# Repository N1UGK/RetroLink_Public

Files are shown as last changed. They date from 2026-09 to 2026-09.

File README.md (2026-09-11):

# RetroLink (POTS Telephone Internet Interface)

RetroLink connects a standard POTS (Plain Old Telephone Service) analog telephone to the Internet over Wi-Fi, allowing peer-to-peer calling between devices and retro telephony interfacing.  The RetroLink is intended for private telephone networks in the same building, campus, or even across the globe.  It will not require subscription fees or a third party "app" or platform to use.  The idea came from my daughter (who is 6) asking for a phone to call her friends.  This device can be configured for connecting a close circle of friends or family and using their chosen "phone number" to dial and connect to them.  Any standard "retro" telephone can be plugged into the RetroLink.

RetroLink

## Overview

RetroLink provides a complete, self-contained telephone line interface for real analog telephones (both rotary and DTMF touch-tone). It generates real ringing voltages, provides line battery feed, detects off-hook and on-hook states, digitizes 2-wire voice audio with hardware codecs, and streams bidirectional voice data over Wi-Fi.

## Key Features

- **True POTS Line Interface**: Powered by the **Silvertel Ag1170-S5** SLIC with an onboard DC/DC converter generating -48V loop battery and 65Vrms ringing directly from a 5V supply.
- **Hardware Voice Codec**: **Texas Instruments TLV320AIC1110** providing 8 kHz PCM sampling, companded G.711 µ-law encoding, digital PGA gain control, and programmable sidetone.
- **Microcontroller**: **Raspberry Pi Pico 2 W** (RP2350 with dual ARM Cortex-M33 / Hazard3 RISC-V cores and onboard CYW43 Wi-Fi).
- **Dual-Core Architecture**:
  - **Core 0**: Real-time audio engine with DMA/PIO double buffering, low-latency audio packetization, and SLIC line supervision (hook switch debounce & ring cadence).
  - **Core 1**: CYW43 Wi-Fi stack, lwIP networking, VoIP stream/control protocol, web status interface, and OLED display navigation.
- **User Interface**:
  - 128x64 SSD1306 OLED display via I2C (0x3C)
  - 4-button tactile keypad (Up, Down, OK, Back) via MAX7329 GPIO expander (0x3A)
  - 7 Status LEDs (Off-Hook, MicroSD, Voice Mail, Ringing, Connected, Wi-Fi Link, Error) via MAX7329 (0x38)
- **Local Storage & USB**:
  - MicroSD card slot over SPI0 with FatFS for address books, call logs, and voicemail storage.
  - TinyUSB USB Mass Storage support for mounting the SD card on a PC or Mac.
- **Web Dashboard & Control**:
  - Embedded HTTP server for real-time OLED screen viewing, virtual button control, device status, and network configuration.
- **Secure Firmware Updates**:
  - Dedicated 64 KB custom bootloader with OTP key verification and drag-and-drop UF2 updates over USB.

## Hardware Specifications

| Component | Specification |
|---|---|
| Microcontroller | Raspberry Pi Pico 2 W (RP2350 @ 150MHz) |
| SLIC Module | Silvertel Ag1170-S5 (5V, 600Ω 2-wire impedance) |
| Ring Generator | Onboard Ag1170 ringing (65Vrms @ 20Hz, REN 3 capable) |
| Voice Codec | TI TLV320AIC1110 (PCM / G.711 µ-law, 8 kHz) |
| Display | 0.96" 128x64 I2C OLED (0x3C) |
| I/O Expanders | 2x MAX7329 I2C Expanders (0x38, 0x3A) |
| Power Supply | Single 18650 Li-Ion Cell with BQ24090 Charger & MCP1642B 5V Boost |
| Connector | Standard RJ-11 6P4C Modular Phone Jack |

## Firmware Updates

To update the firmware:
1. Place RetroLink into bootloader mode via the OLED menu: `Settings -> Update Firmware`, or hold the bootsel/startup button combo on power-up.
2. Connect RetroLink to your computer via USB. A mass-storage drive named `RETROLINK` will appear.
3. Drag and drop the latest release `.uf2` file from the `Firmware/` folder onto the drive.
4. The bootloader will verify and flash the image, then automatically reboot into the new firmware.

## Repository Structure

- `Firmware/`: Official firmware release binaries (`.uf2`) and release notes.
- `Hardware/`: 3D CAD STEP models, schematics, and mechanical design files.
- `Documentation/`: User guides, application notes, and reference manuals.
>>>>>>> b99fa2f (Initial commit for RetroLink_Public repository structure)

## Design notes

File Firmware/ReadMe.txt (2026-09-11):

RetroLink Firmware Release Notes

Note - In order to update the firmware, you will need to place the RetroLink into bootloader mode. This can be done via the OLED display menu: Settings -> Update Firmware, or by holding the configured startup button combination on power-up.

RetroLink will reboot into its bootloader mode. Plug RetroLink into a Mac or PC with a USB cable, and drag and drop the firmware file onto the removable drive that appears.

The RetroLink bootloader will decrypt the firmware file, verify the signature, and if it passes, it will flash the image and reboot.

Note that the RetroLink bootloader is distinct from the default RP2350 ROM bootloader — if you use the BOOTSEL button on the Pico 2 W directly, the ROM bootloader cannot decrypt signed RetroLink firmware images. You can determine which bootloader is active by checking the directory contents of the USB drive:
- If you see `RetroLink.txt` / `INFO_UF2.TXT` with RetroLink identifiers, you are in the RetroLink Custom Bootloader.
- If you see default Raspberry Pi files, you are in the RP2350 ROM bootloader.

--------------------------------------------------------------------------------
09-11-2026 - RetroLink_V1.00_B0001.uf2

- Initial firmware release shell for RetroLink (Raspberry Pi Pico 2 W / RP2350).
- Drivers:
  - Ag1170 SLIC: hook switch detection, debounce, ring-trip auto-cancel, 20Hz ring cadence generator, power down.
  - TLV320AIC1110 voice codec: 8 kHz PCM sampling, I2C register configuration, PGA volume/gain controls.
  - SSD1306 128x64 OLED display: real-time status display and menu navigation.
  - MAX7329 I/O expanders: 4 tactile buttons and 7 status LEDs (OH, SD, VM, RNG, CON, LNK, ERR).
  - SD Card / FatFS: SPI0 storage with USB Mass Storage bridge.
  - Wi-Fi & Web UI: CYW43 Wi-Fi connection, SNTP network time sync, and remote HTTP status dashboard.

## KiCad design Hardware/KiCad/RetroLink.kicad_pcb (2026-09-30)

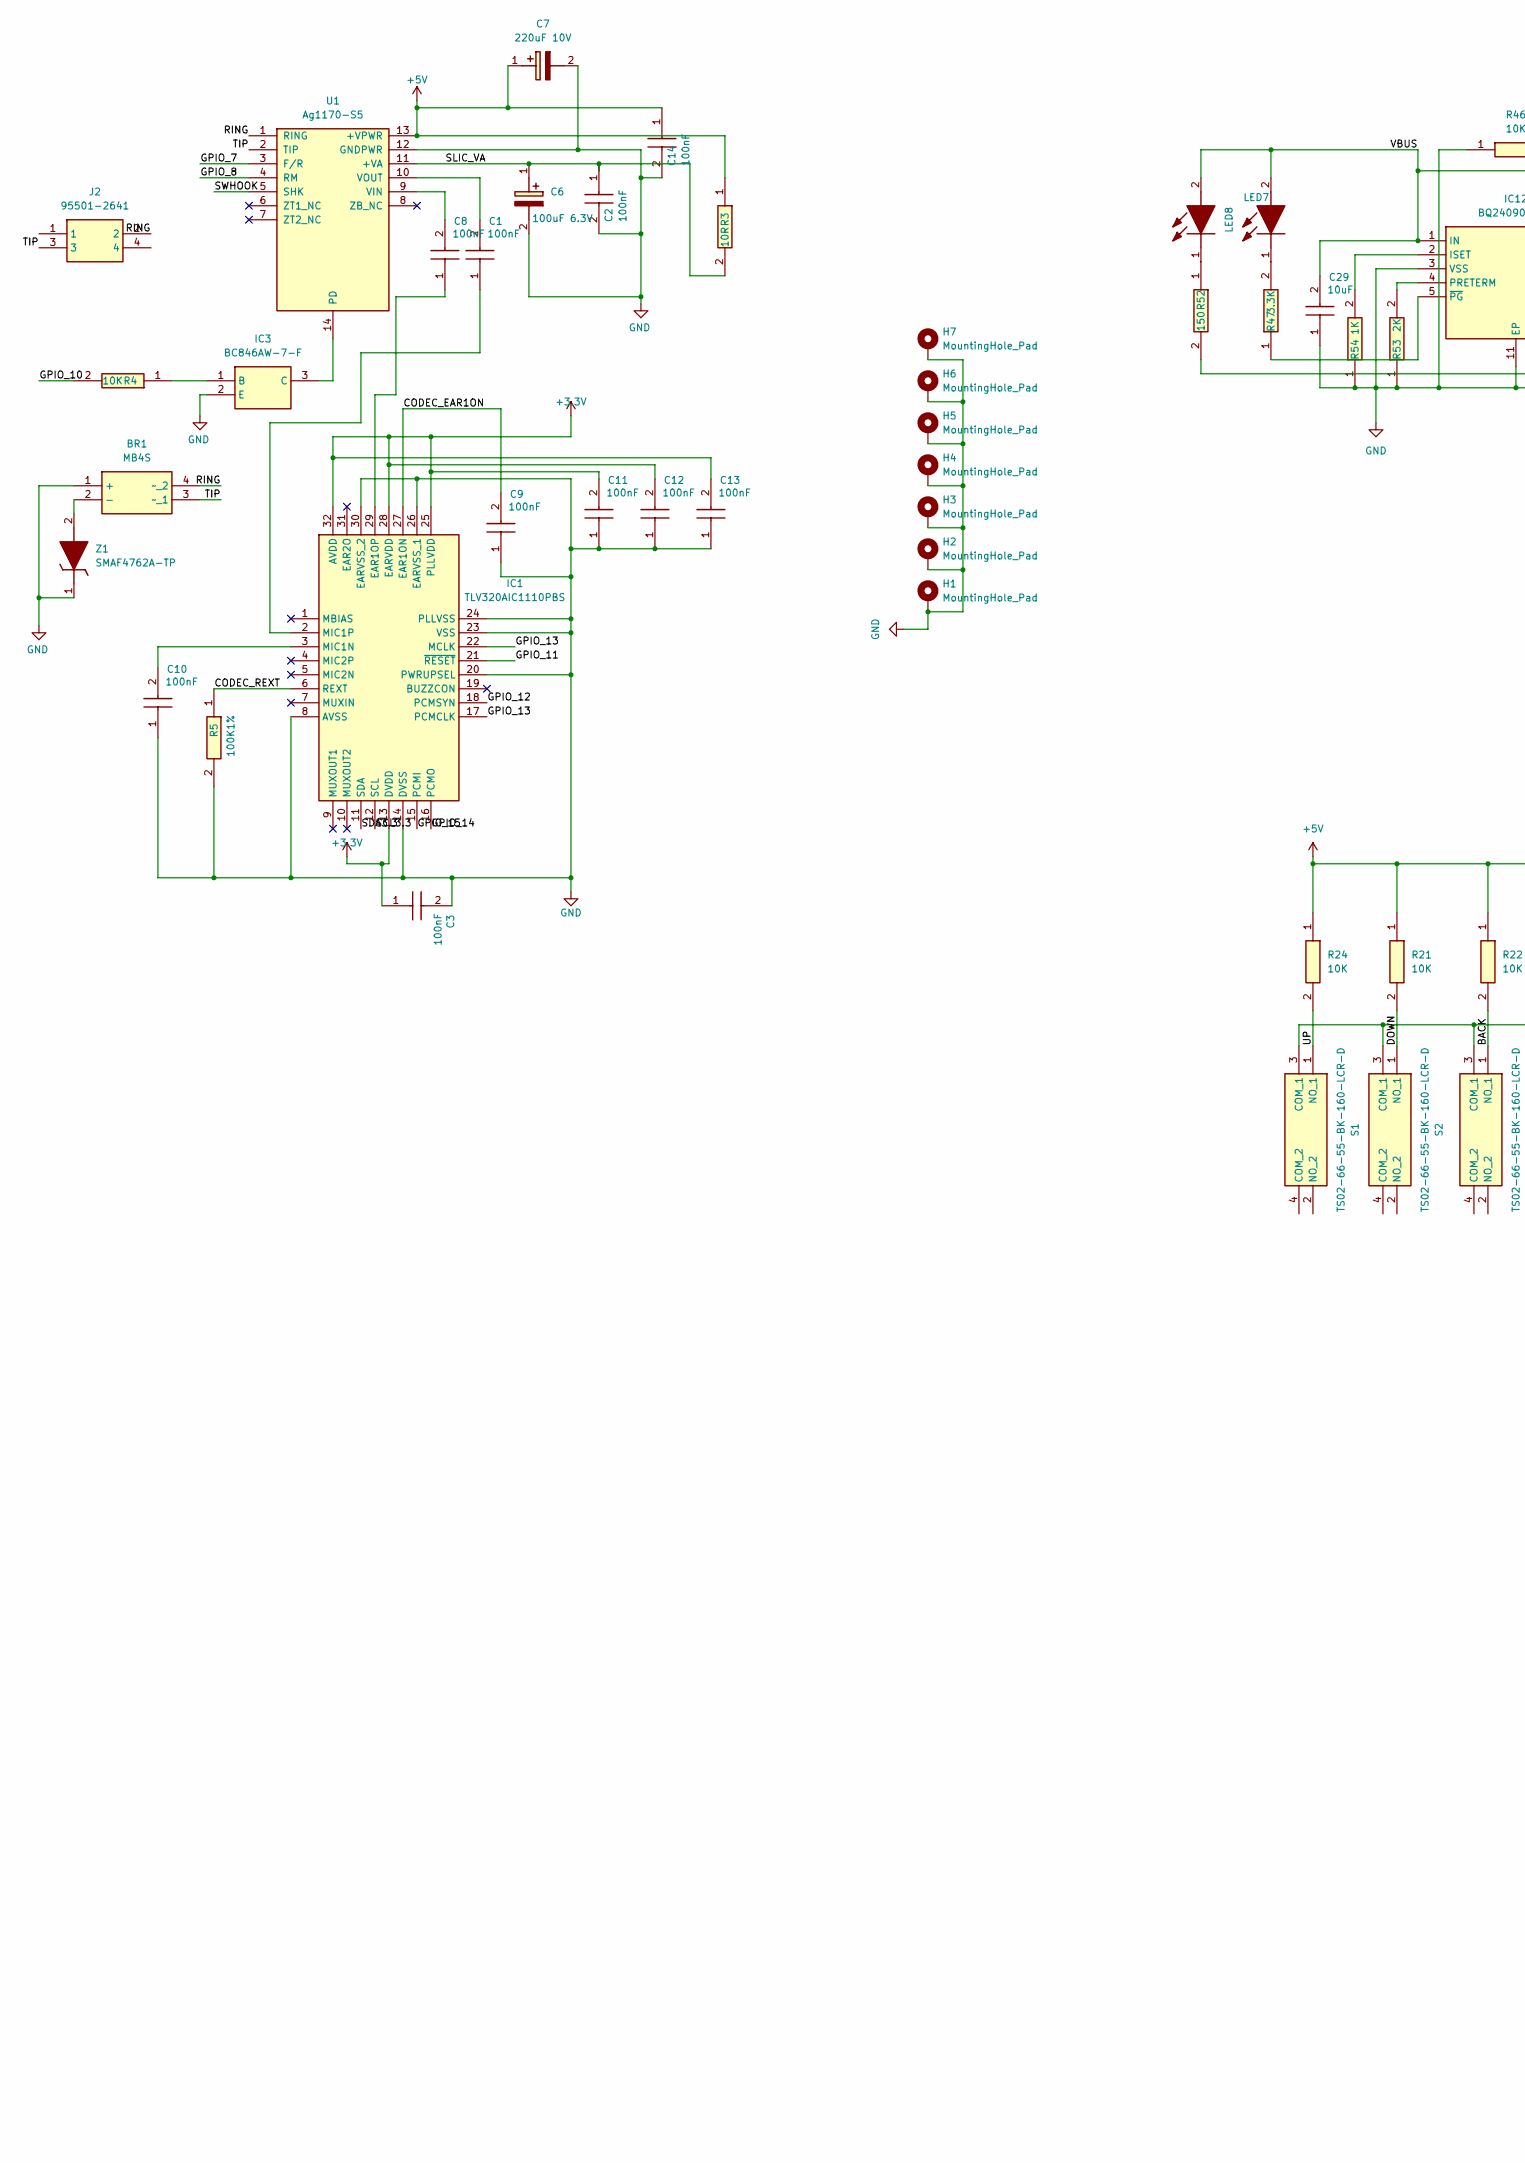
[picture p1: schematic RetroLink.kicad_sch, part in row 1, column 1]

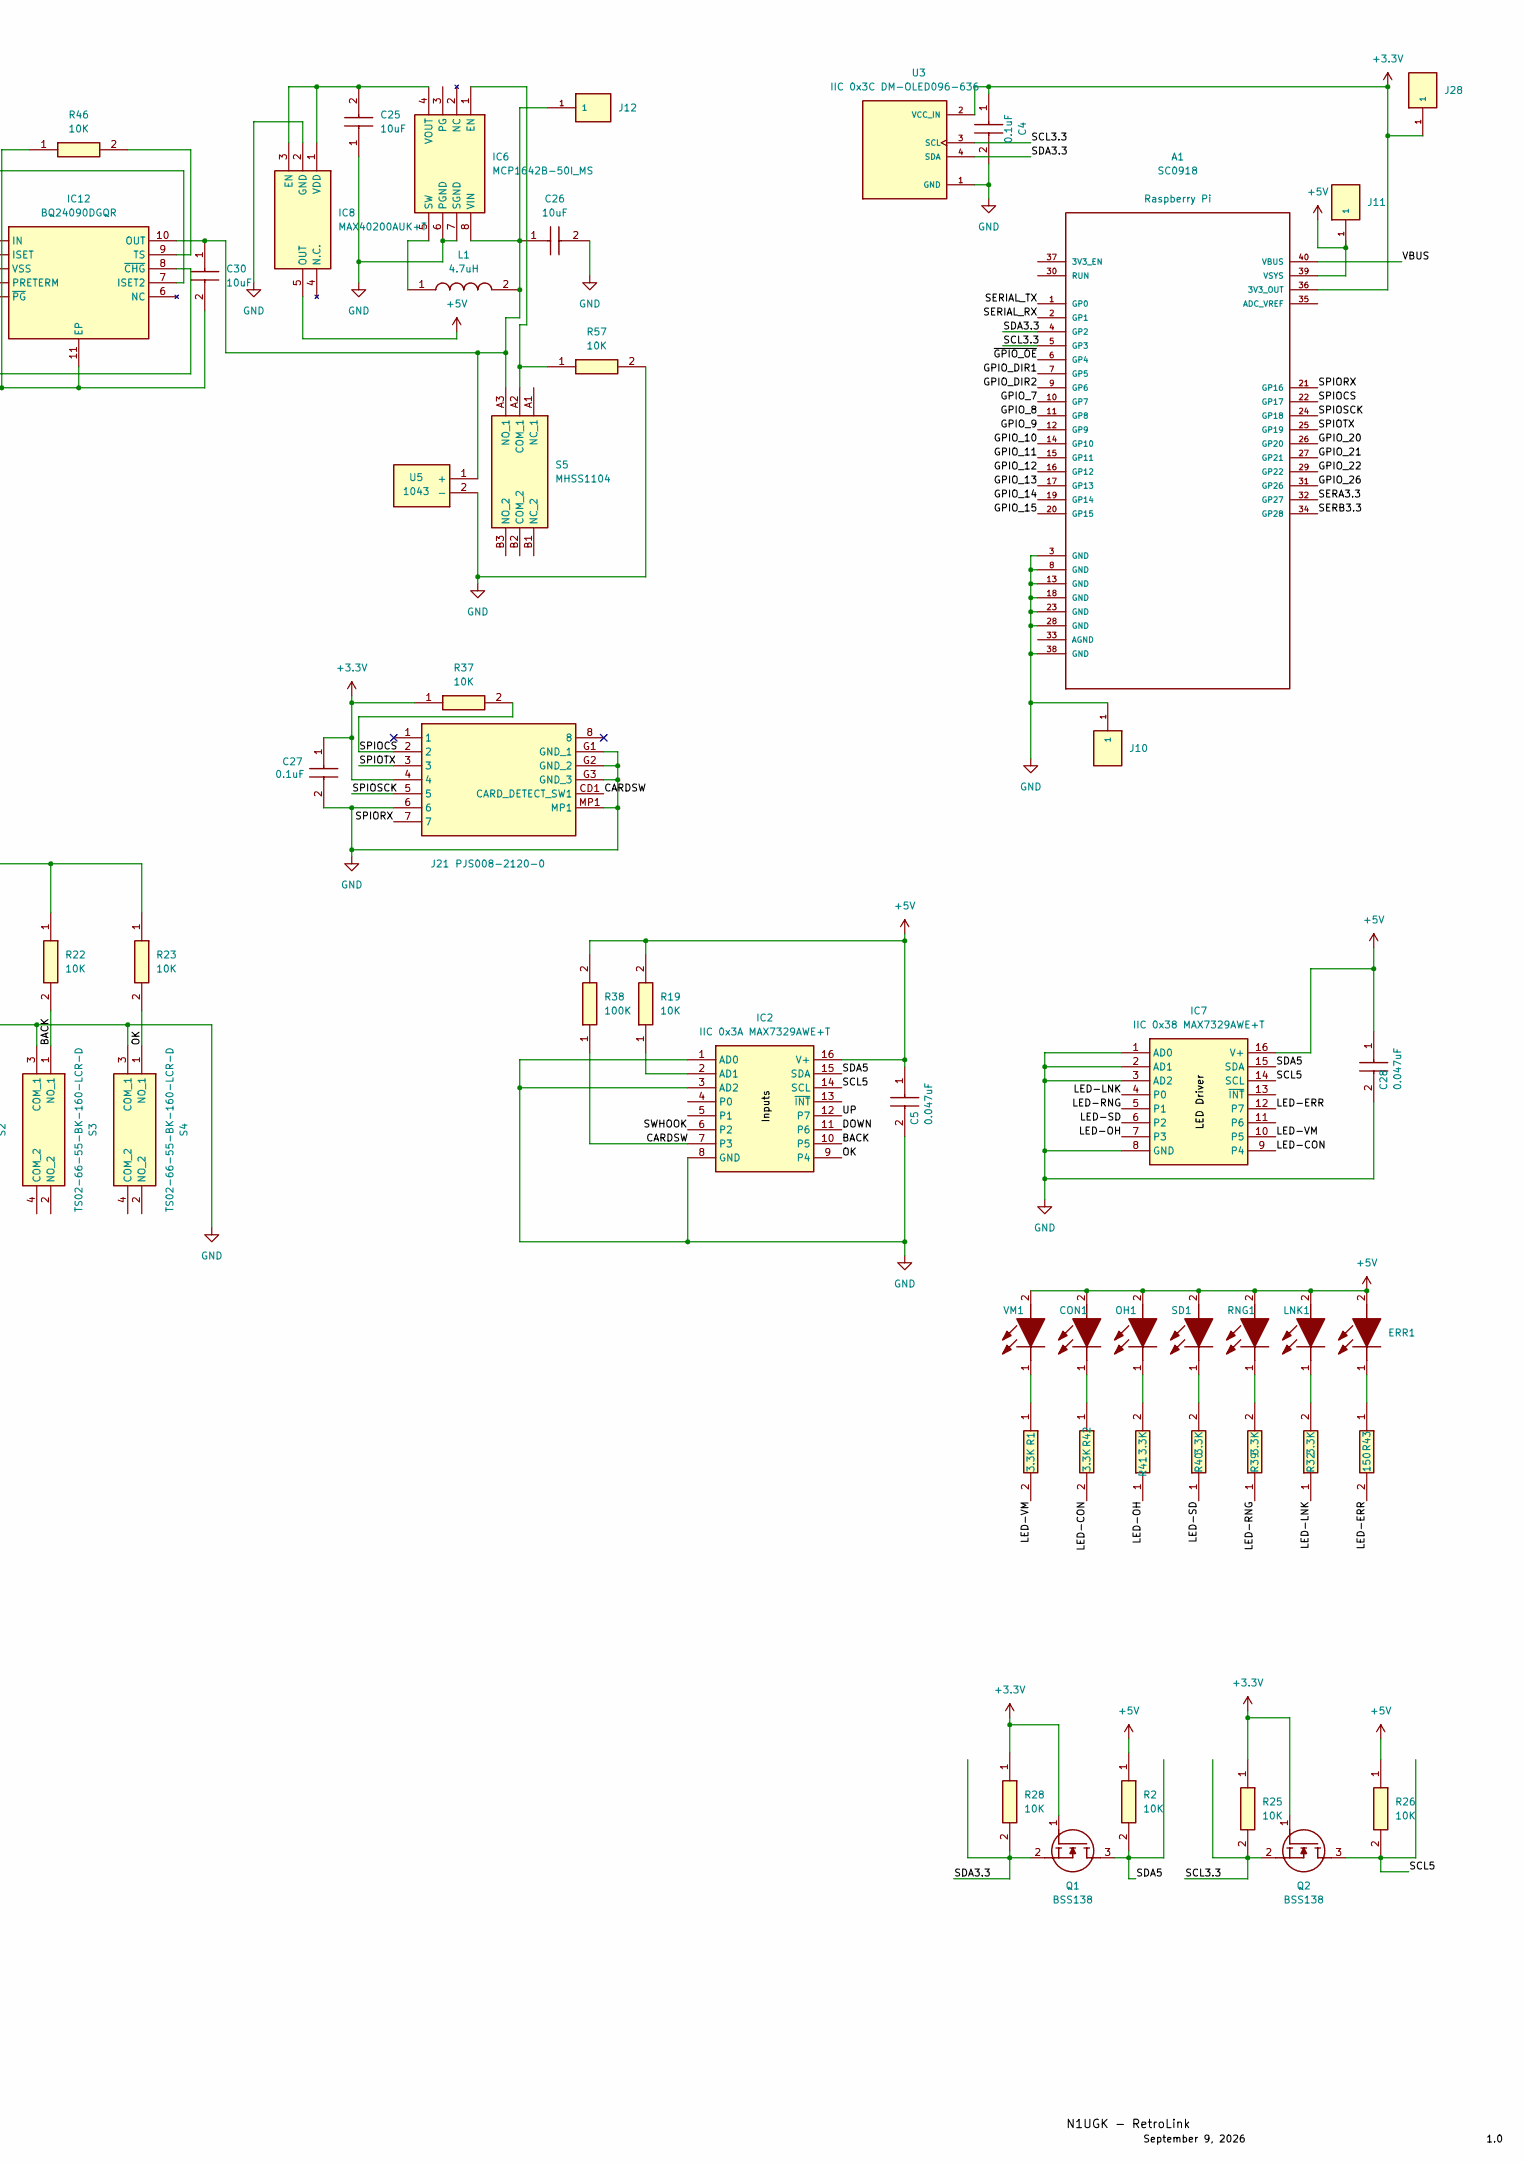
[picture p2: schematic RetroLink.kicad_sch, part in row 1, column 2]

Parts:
A1: SC0918; MODULE_SC0918; PARTREV 1.6
BR1: MB4S; SOP245P670X290-4N; Mouser Part Number 512-MB4S
C1, C3, C8, C9, C10, C11, C12, C13: 100nF; CAPC1608X90N; Mouser Part Number 81-GRM188R60J106ME4D
C2, C14: 100nF; C1206; Mouser Part Number 80-C1206C473J5R
C4: 0.1uF; CAPC3216X229N; Mouser Part Number 581-12063G106ZAT2A
C5, C28: 0.047uF; C1206; Mouser Part Number 80-C1206C473J5R
C6: 100uF 6.3V; CAPPRD200W50D500H1250; Mouser Part Number 80-ESK107M025AC3AA
C7: 220uF 10V; CAPPRD250W50D655H1250; Mouser Part Number 232-16ZLH220MEFC63X1
C25, C26, C29, C30: 10uF; CAPC1608X90N; Mouser Part Number 81-GRM188R60J106ME4D
C27: 0.1uF; CAPC3216X94N; Mouser Part Number 581-12061C103J
CON1: HSMM-A100-S00J1; LEDM3528X200N; Mouser Part Number 630-HSMM-A100-S00J1
ERR1: HSMS-A100-L00J1; HSMSA100L00J1; Mouser Part Number 630-HSMS-A100-L00J1
H1, H2, H3, H4, H5, H6, H7: MountingHole_Pad; MountingHole_3.2mm_M3_Pad_Via
IC1: TLV320AIC1110PBS; QFP50P700X700X120-32N; Mouser Part Number 595-TLV320AIC1110PBS
IC2: IIC 0x3A MAX7329AWE+T; SOIC127P1032X265-16N; Mouser Part Number 700-MAX7329AWET
IC3: BC846AW-7-F; SOT65P210X110-3N; Mouser Part Number 621-BC846AW-7-F
IC6: MCP1642B-50I_MS; SOP65P490X110-8N; Mouser Part Number 579-MCP1642B-50I/MS
IC7: IIC 0x38 MAX7329AWE+T; SOIC127P1032X265-16N; Mouser Part Number 700-MAX7329AWET
IC8: MAX40200AUK+T; SOT95P280X145-5N; Mouser Part Number 700-MAX40200AUK+T
IC12: BQ24090DGQR; SOP50P490X110-11N; Mouser Part Number 595-BQ24090DGQR
J2: 95501-2641; 955012641; Mouser Part Number 538-95501-2641
J10, J11, J12, J28: SAMTEC-HMTSW-101-24-X-S-290
J21: PJS008-2120-0; PJS00821200; Mouser Part Number 945-PJS008-2120-0
L1: 4.7uH; EPL3015472MLC; Mouser Part Number 994-EPL3015-472MLC
LED7: HSMM-A100-S00J1; LEDM3528X200N; Mouser Part Number 630-HSMM-A100-S00J1
LED8: HSMS-A100-L00J1; HSMSA100L00J1; Mouser Part Number 630-HSMS-A100-L00J1
LNK1: HSMM-A100-S00J1; LEDM3528X200N; Mouser Part Number 630-HSMM-A100-S00J1
OH1: HSMM-A100-S00J1; LEDM3528X200N; Mouser Part Number 630-HSMM-A100-S00J1
Q1, Q2: BSS138; SOT95P240X120-3N; Mouser Part Number 512-BSS138
R1, R32, R39, R40, R41, R42, R47: 3.3K; RESC2013X65N; Mouser Part Number 756-WCR0805-10KFI
R2, R4, R19, R21, R22, R23, R24, R25, R26, R28, R37, R46, R57: 10K; RESC2013X65N; Mouser Part Number 756-WCR0805-10KFI
R3: 10R; RESC2013X65N; Mouser Part Number 756-WCR0805-10KFI
R5: 100K1%; RESC2013X65N; Mouser Part Number 756-WCR0805-10KFI
R38: 100K; RESC2013X65N; Mouser Part Number 756-WCR0805-10KFI
R43, R52: 150; RESC2013X65N; Mouser Part Number 756-WCR0805-10KFI
R53: 2K; RESC2013X65N; Mouser Part Number 756-WCR0805-10KFI
R54: 1K; RESC2013X65N; Mouser Part Number 756-WCR0805-10KFI
RNG1: HSMM-A100-S00J1; LEDM3528X200N; Mouser Part Number 630-HSMM-A100-S00J1
S1, S2, S3, S4: TS02-66-55-BK-160-LCR-D; TS026655BK160LCRD; Mouser Part Number 179-TS026655BK160LCR
S5: MHSS1104; Mouser Part Number 642-MHSS1104
SD1: HSMM-A100-S00J1; LEDM3528X200N; Mouser Part Number 630-HSMM-A100-S00J1
U1: Ag1170-S5
U3: IIC 0x3C DM-OLED096-636; MODULE_DM-OLED096-636; PARTREV 2018-09-10
U5: 1043; Mouser Part Number 534-1043
VM1: HSMM-A100-S00J1; LEDM3528X200N; Mouser Part Number 630-HSMM-A100-S00J1
Z1: SMAF4762A-TP; SODFL5026X125N; Manufacturer_Part_Number SMAF4762A-TP

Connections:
+3.3V: A1.36 (3V3_OUT), C3.1, C4.1, C11.2, C12.2, C13.2, C27.1 (C1), IC1.13 (DVDD), IC1.25 (PLLVDD), IC1.28 (EARVDD), IC1.32 (AVDD), J21.4, J28.1, Q1.1 (G), Q2.1 (G), R25.1, R28.1, R37.1, U3.2 (VCC_IN)
+5V: A1.39 (VSYS), C5.1, C7.1 (+), C14.1, C28.1, CON1.2 (A), ERR1.2 (A), IC2.16 (V+), IC7.16 (V+), IC8.5 (OUT), J11.1, LNK1.2 (A), OH1.2 (A), R2.1, R3.1, R19.2, R21.1, R22.1, R23.1, R24.1, R26.1, R38.2, RNG1.2 (A), SD1.2 (A), U1.13 (+VPWR), VM1.2 (A)
/BACK: IC2.10 (P5), R22.2, S3.1 (NO_1)
/CARDSW: IC2.7 (P3), J21.CD1 (CARD_DETECT_SW1), R38.1
/CODEC_EAR1ON: C9.2, IC1.27 (EAR1ON)
/CODEC_REXT: IC1.6 (REXT), R5.1
/DOWN: IC2.11 (P6), R21.2, S2.1 (NO_1)
/GPIO_7: A1.10 (GP7), U1.3 (F/R)
/GPIO_8: A1.11 (GP8), U1.4 (RM)
/GPIO_10: A1.14 (GP10), R4.2
/GPIO_11: A1.15 (GP11), IC1.21 (~RESET)
/GPIO_12: A1.16 (GP12), IC1.18 (PCMSYN)
/GPIO_13: A1.17 (GP13), IC1.17 (PCMCLK), IC1.22 (MCLK)
/GPIO_14: A1.19 (GP14), IC1.16 (PCMO)
/GPIO_15: A1.20 (GP15), IC1.15 (PCMI)
/GPIO_20: A1.26 (GP20)
/GPIO_21: A1.27 (GP21)
/GPIO_22: A1.29 (GP22)
/GPIO_26: A1.31 (GP26)
/GPIO_DIR1: A1.7 (GP5)
/GPIO_DIR2: A1.9 (GP6)
/LED-CON: IC7.9 (P4), R42.2
/LED-ERR: IC7.12 (P7), R43.2
/LED-LNK: IC7.4 (P0), R32.1
/LED-OH: IC7.7 (P3), R41.1
/LED-RNG: IC7.5 (P1), R39.1
/LED-SD: IC7.6 (P2), R40.1
/LED-VM: IC7.10 (P5), R1.2
/OK: IC2.9 (P4), R23.2, S4.1 (NO_1)
/RING: BR1.4 (~_2), J2.2, U1.1 (RING)
/SCL3.3: A1.5 (GP3), IC1.12 (SCL), Q2.2 (S), R25.2, U3.3 (SCL)
/SCL5: IC2.14 (SCL), IC7.14 (SCL), Q2.3 (D), R26.2
/SDA3.3: A1.4 (GP2), IC1.11 (SDA), Q1.2 (S), R28.2, U3.4 (SDA)
/SDA5: IC2.15 (SDA), IC7.15 (SDA), Q1.3 (D), R2.2
/SERA3.3: A1.32 (GP27)
/SERB3.3: A1.34 (GP28)
/SERIAL_RX: A1.2 (GP1)
/SERIAL_TX: A1.1 (GP0)
/SLIC_VA: C2.1, C6.1 (+), R3.2, U1.11 (+VA)
/SPIOCS: A1.22 (GP17), J21.2, R37.2
/SPIORX: A1.21 (GP16), J21.7
/SPIOSCK: A1.24 (GP18), J21.5
/SPIOTX: A1.25 (GP19), J21.3
/TIP: BR1.3 (~_1), J2.3, U1.2 (TIP)
/UP: IC2.12 (P7), R24.2, S1.1 (NO_1)
/VBUS: A1.40 (VBUS), C29.2, IC12.1 (IN), IC12.7 (ISET2), LED7.2 (A), LED8.2 (A)
/~GPIO_OE: A1.6 (GP4)
GND: A1.3 (GND), A1.8 (GND), A1.13 (GND), A1.18 (GND), A1.23 (GND), A1.28 (GND), A1.38 (GND), BR1.1 (+), C2.2, C3.2, C4.2, C5.2, C6.2 (-), C7.2 (-), C9.1, C10.1, C11.1, C12.1, C13.1, C14.2, C25.1, C26.2, C27.2 (C2), C28.2, C29.1, C30.2, H1.1, H2.1, H3.1, H4.1, H5.1, H6.1, H7.1, IC1.8 (AVSS), IC1.14 (DVSS), IC1.20 (PWRUPSEL), IC1.23 (VSS), IC1.24 (PLLVSS), IC1.26 (EARVSS_1), IC1.30 (EARVSS_2), IC2.1 (AD0), IC2.3 (AD2), IC2.8 (GND), IC3.2 (E), IC6.6 (PGND), IC6.7 (SGND), IC7.1 (AD0), IC7.2 (AD1), IC7.3 (AD2), IC7.8 (GND), IC8.2 (GND), IC12.3 (VSS), IC12.11 (EP), J10.1, J21.6, J21.G1 (GND_1), J21.G2 (GND_2), J21.G3 (GND_3), J21.MP1, R5.2, R46.1, R53.1, R54.1, R57.2, S1.3 (COM_1), S2.3 (COM_1), S3.3 (COM_1), S4.3 (COM_1), U1.12 (GNDPWR), U3.1 (GND), U5.2 (-), Z1.1 (K)
unnamed: BR1.2 (-), Z1.2 (A)
unnamed: CON1.1 (K), R42.1
unnamed: ERR1.1 (K), R43.1
unnamed: C8.1, IC1.29 (EAR1OP)
unnamed: C10.2, IC1.3 (MIC1N)
unnamed: C1.1, IC1.2 (MIC1P)
unnamed: IC2.2 (AD1), R19.1
unnamed: IC3.1 (B), R4.1
unnamed: IC3.3 (C), U1.14 (PD)
unnamed: IC6.1 (EN), R57.1, S5.A2 (COM_1)
unnamed: IC6.5 (SW), L1.1
unnamed: C25.2, IC6.4 (VOUT), IC8.1 (VDD), IC8.3 (EN)
unnamed: IC12.2 (ISET), R54.2
unnamed: C26.1, C30.1, IC6.8 (VIN), IC12.10 (OUT), J12.1, L1.2, S5.A3 (NO_1), U5.1 (+)
unnamed: IC12.4 (PRETERM), R53.2
unnamed: IC12.9 (TS), R46.2
unnamed: IC12.8 (~CHG), R52.2
unnamed: IC12.5 (~PG), R47.1
unnamed: LED7.1 (K), R47.2
unnamed: LED8.1 (K), R52.1
unnamed: LNK1.1 (K), R32.2
unnamed: OH1.1 (K), R41.2
unnamed: R39.2, RNG1.1 (K)
unnamed: R40.2, SD1.1 (K)
unnamed: C8.2, U1.9 (VIN)
unnamed: C1.2, U1.10 (VOUT)
unnamed: R1.1, VM1.1 (K)

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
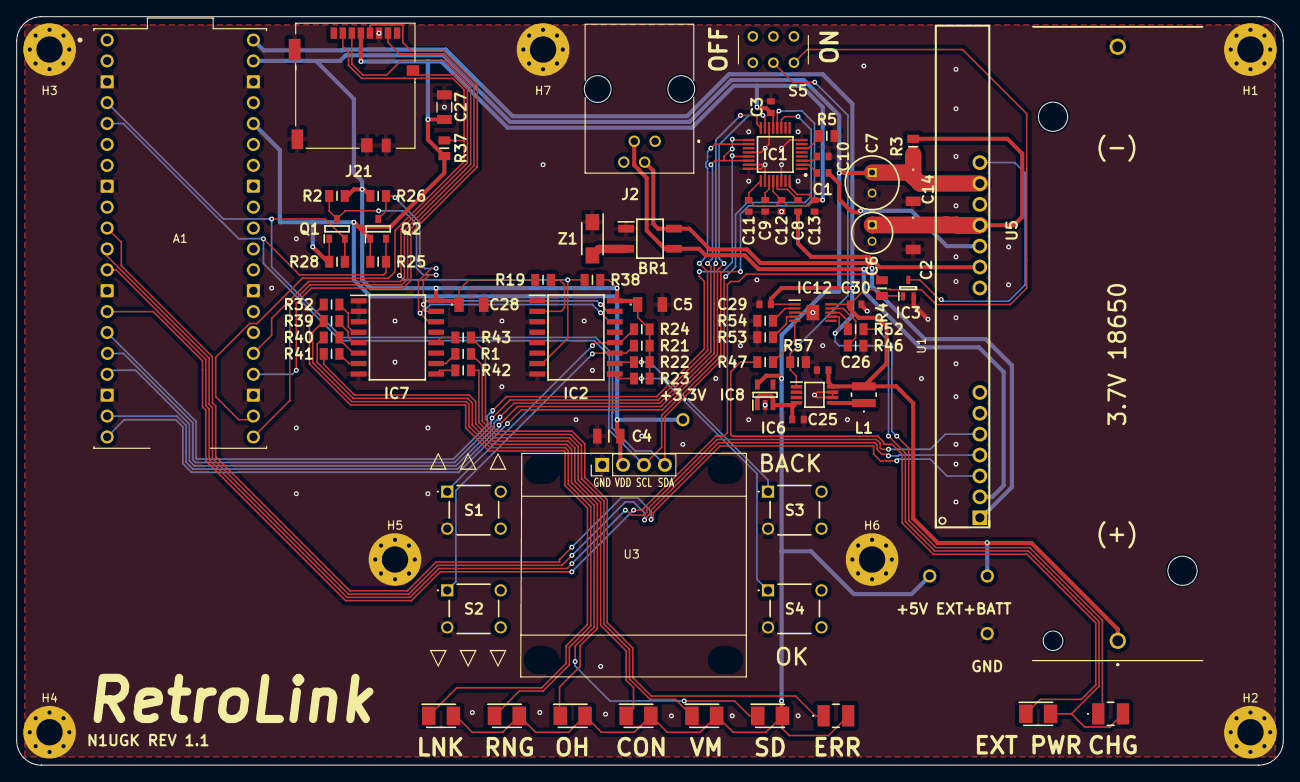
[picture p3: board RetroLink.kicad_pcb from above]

Board: 2 copper layers, 154.0 x 91.0 mm, 90 parts (0 on the bottom side), 65 nets.

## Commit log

2026-09-30 Added Rev1.1
    [RetroLink.kicad_pcb, RetroLink.kicad_sch]
2026-10-27 Updated PCB and STEP export.
2026-10-30 Updates to case
2026-10-31 Fixes to bottom case, added buttons
2026-11-04 Case updates
